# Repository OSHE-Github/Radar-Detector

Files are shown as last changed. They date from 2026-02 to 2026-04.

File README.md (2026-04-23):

# Radar-Detector

## Project Details
#### a fully open-source radar detector that can be easily replicated by others. Unlike existing commercial solutions, which are proprietary, this design will provide transparency, customization, and accessibility to users. By creating the first truly open-source radar detector, the project expands available options for individuals interested in building, modifying, or better understanding radar detection technology.
#### This device is powered by the 12V port that's in every commercial vehicle by using a 5V adapter and USB-C connector on board.

## Current State
#### The current Design includes
#### - Completed RF and Control Board
#### - Completed Antenna and Waveguide
#### - A breadboarded circuit for K band detection

## Semester End Report
#### For the Enterprise Program at Michigan Tech there is a end of semester report for the project to summarize the progress of the project. [Link](https://docs.google.com/document/d/1saLg0oObQiK9GF-1CGu6zWZuvDCvK0RMIuFfh2jqqCw/edit?usp=sharing)

## Relevant Standards
#### - Traces Were sized appropriately for current being drawn
#### - No traces can be ran under the main RF lines
#### - There was fusing put in front of the main power input from the USB-C
#### - Decoupling capacitors used to reduce noise from voltage sources going into sensitive components

## Constraints of Design
#### - when working with high frequencies up to 40GHz you have to use special small components that can handle it
#### - The material to make a PCB that can handle that high of frequencies is very expensive
#### - Amplifiers for this frequency are very expensive

## Next Semester Goals
#### - Look into possible cheaper solutions using modules like what we found for the K band
#### - Test the Ka band implementation once we have the antenna
#### - Look into the design on the component for the K band and see if parts of it are re-creatable

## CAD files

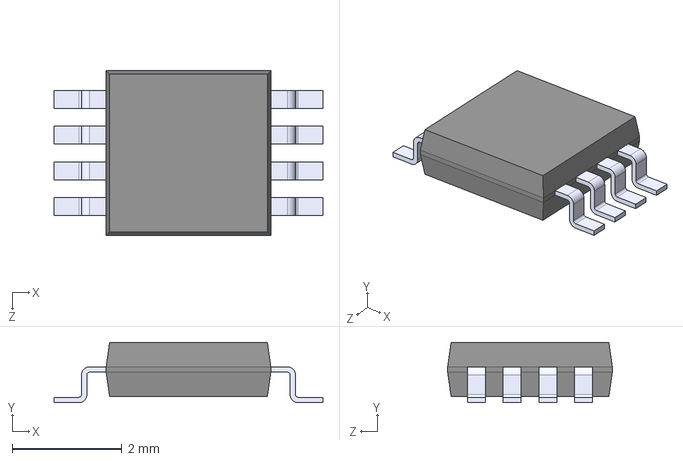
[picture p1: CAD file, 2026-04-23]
Front-End KiCad/Radar_Detector/FINAL - UPPER RF BOARD/AD8314ARMZ.step
4.90 x 1.10 x 3.00 mm

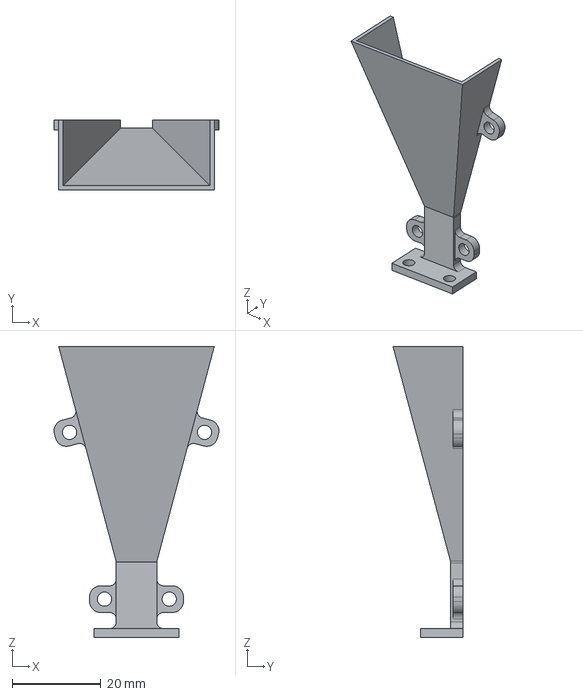
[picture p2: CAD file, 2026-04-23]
Horn Antenna/Horn Antenna & Waveguide Final/AntennaTOPFillet.step
37.1 x 15.8 x 65.4 mm

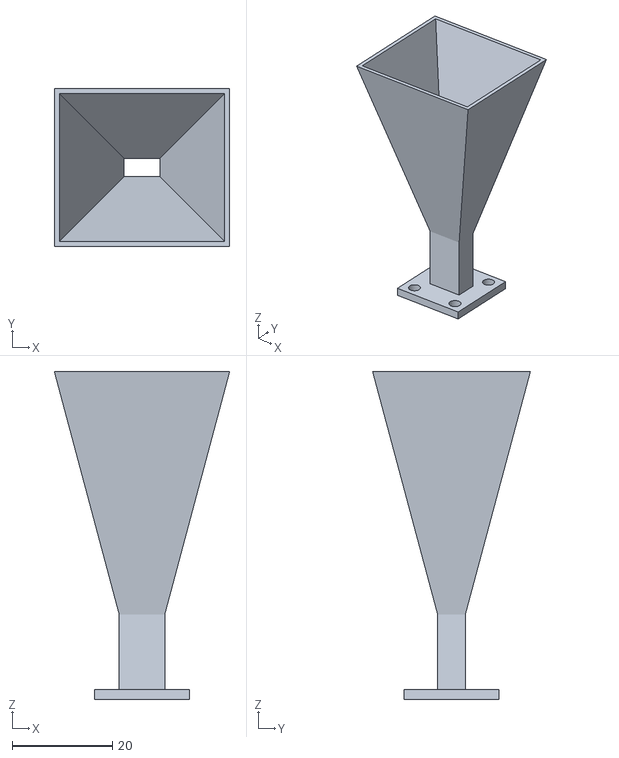
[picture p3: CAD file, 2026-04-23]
Horn Antenna/Horn Antenna V4/HornAntennaV4.stl
35.0 x 31.5 x 65.4

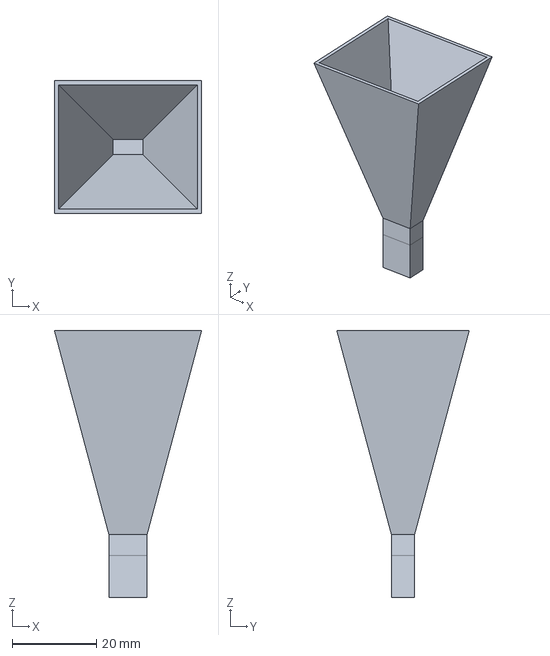
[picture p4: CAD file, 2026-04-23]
Horn Antenna/Horrn Antenna V5/HornAntennaV5_Rough Draft.FCStd
35.0 x 31.5 x 63.4 mm

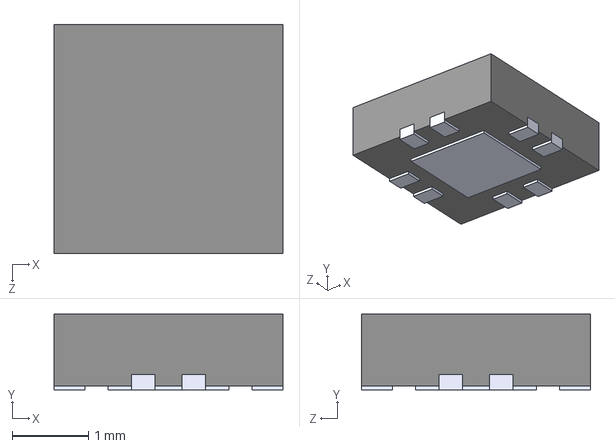
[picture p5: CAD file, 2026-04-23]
Front-End KiCad/Radar_Detector/FINAL - UPPER RF BOARD/PMA-5451_.step
3.00 x 0.99 x 3.00 mm

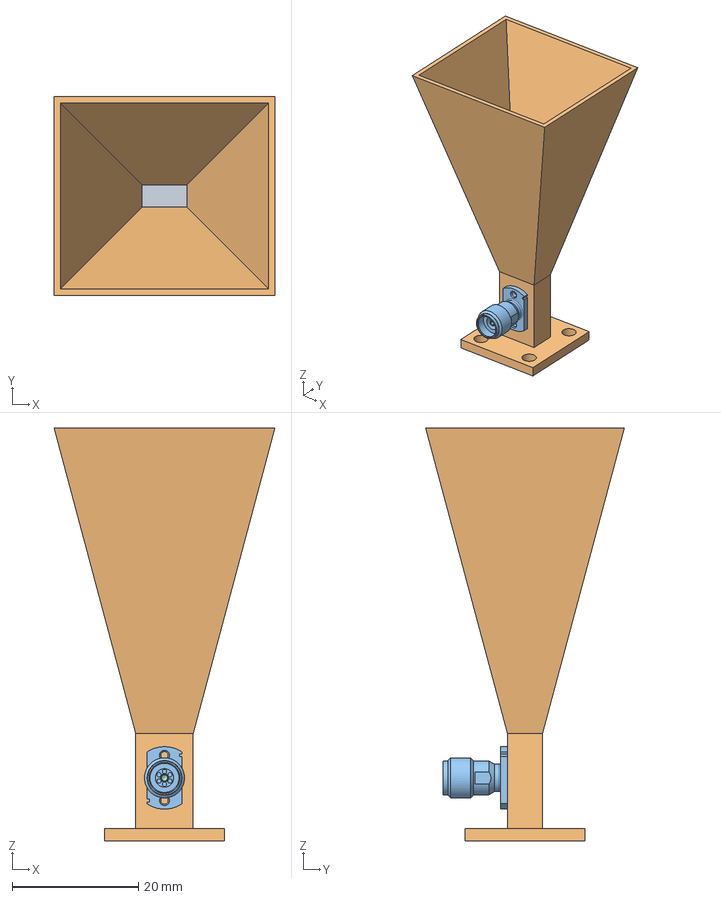
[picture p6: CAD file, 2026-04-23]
Horn Antenna/Horrn Antenna V5/HornAntennaV5_WithCOAX.FCStd
35.0 x 31.5 x 65.4 mm
292-J-P-EP-ST-CM-1_BODY
292-J-P-CM_PIN

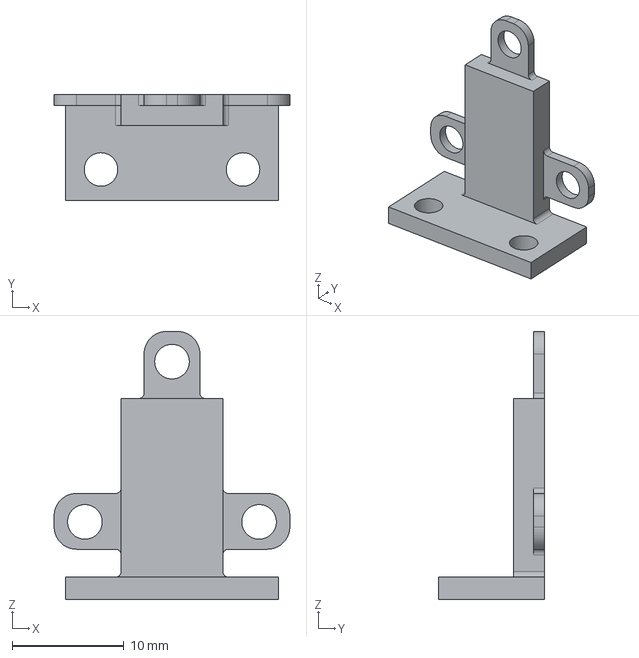
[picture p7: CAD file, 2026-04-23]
Horn Antenna/Horn Antenna & Waveguide Final/WaveguideBOTFillet.step
21.1 x 9.53 x 24.0 mm

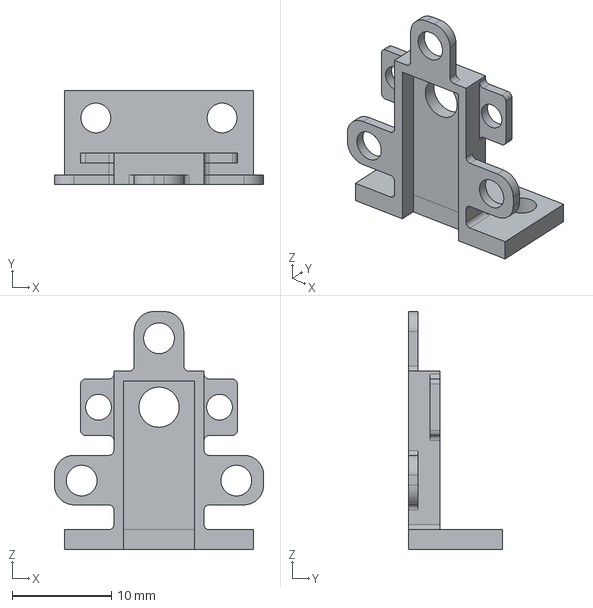
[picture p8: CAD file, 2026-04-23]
Horn Antenna/Horn Antenna & Waveguide Final/WaveguideTOPFillet.step
21.1 x 9.53 x 24.0 mm

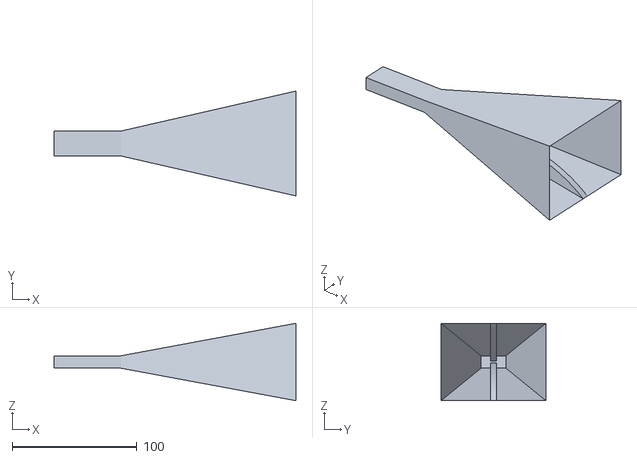
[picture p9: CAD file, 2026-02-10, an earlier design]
Horn Antenna/Horn Antenna V2/3D Models/8_40Ghz_Scaled.stl
193.8 x 84.0 x 62.0

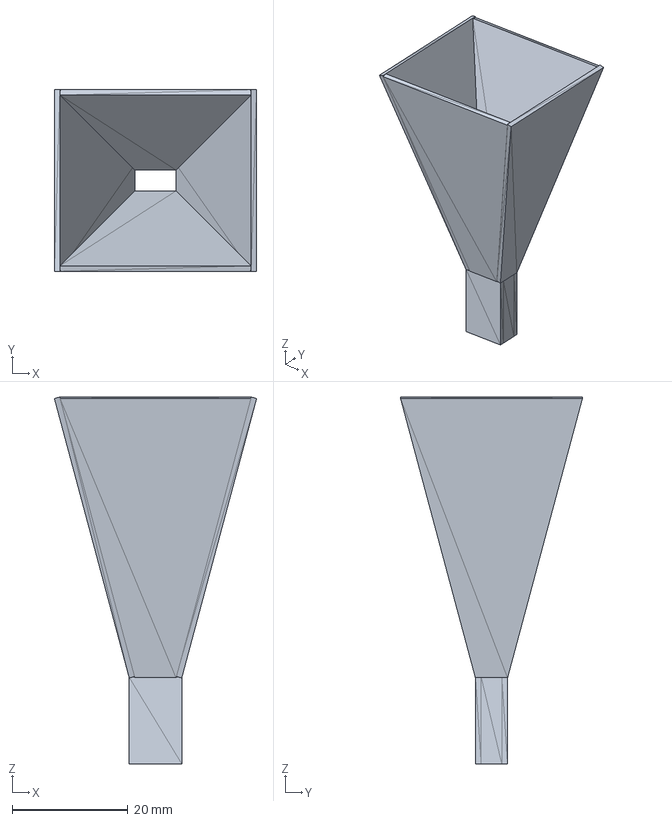
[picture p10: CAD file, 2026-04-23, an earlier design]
Horn Antenna/Horn Antenna V3/3D Models/HornAntennaKA.FCStd
35.0 x 31.4 x 63.4 mm

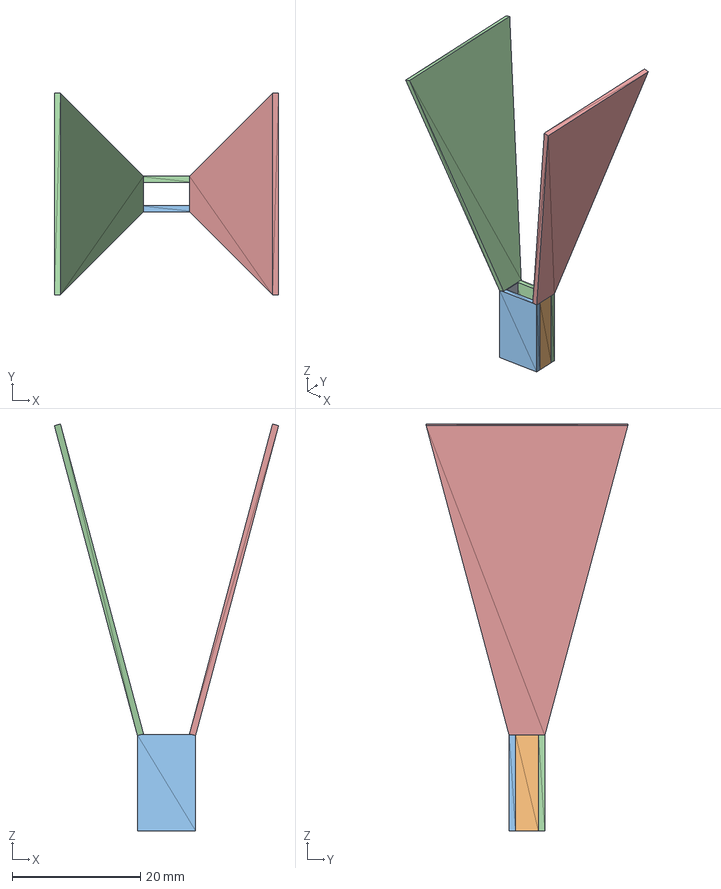
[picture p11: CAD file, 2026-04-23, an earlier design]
Horn Antenna/Horn Antenna V3/3D Models/Unnamed1.FCStd
35.0 x 31.4 x 63.4 mm

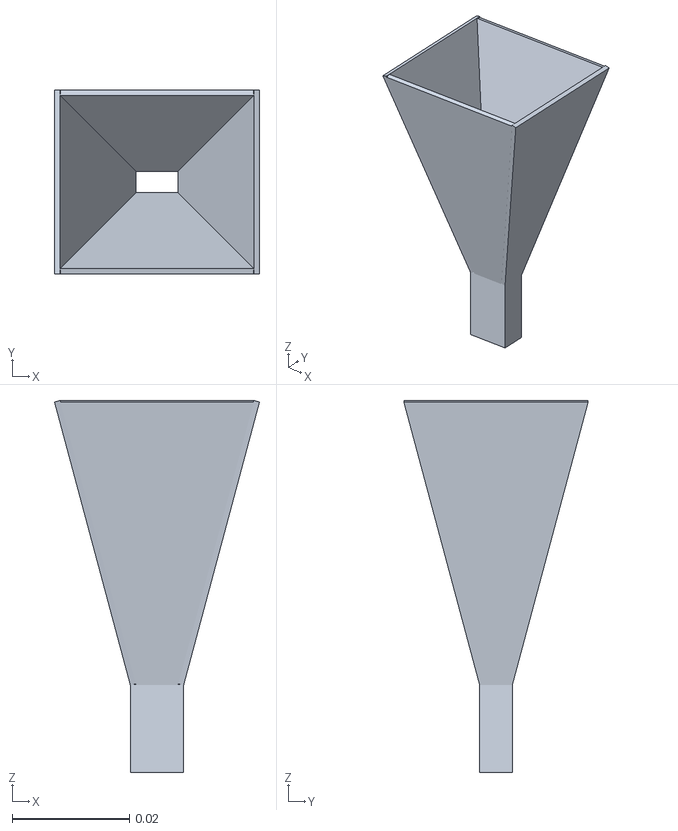
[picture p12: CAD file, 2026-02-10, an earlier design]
Horn Antenna/Horn Antenna V3/3D Models/horn.stl
0.035 x 0.0314 x 0.0634

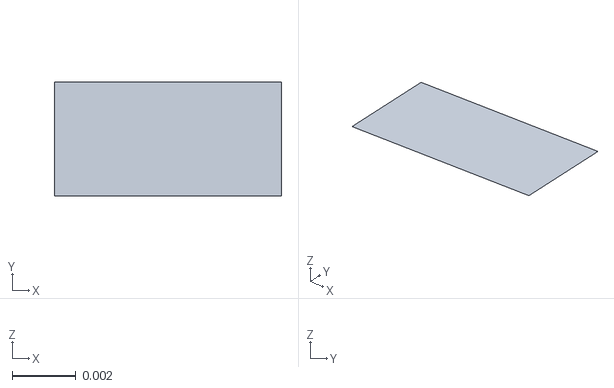
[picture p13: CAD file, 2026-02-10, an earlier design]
Horn Antenna/Horn Antenna V3/3D Models/port_excite_1.stl
0.00711 x 0.00356 x 0

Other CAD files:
Horn Antenna/Horn Antenna & Waveguide Final/AntennaBOTFillet.step
Horn Antenna/Horn Antenna V3/3D Models/Antenna.stp

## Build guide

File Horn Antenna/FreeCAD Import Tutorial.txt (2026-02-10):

How to Import the generated stl file into FreeCAD

1. Create New File, Parametric Part
2. Go to File and then press Import. (or press Ctrl + I)
3. Navigate to Correct Folder and open correct .stl File 

How to Convert Imported Mesh to Solid in FreeCAD

1. Switch Workbench
 1.A. In the top center dropdown menu (which usually says "Start"), switch to the Part Workbench. On modern Versions it may be called just Part

2. In Create Shape Tab
 2.A. Select the antenna mesh in the Model tree (on the left side of the screen).
 2.B. Select Object then, Go to the top menu: Part and Create shape from mesh.
 2.C. A popup will appear asking for "Tolerance for sewing shape." Leave it at 0.10 and click OK.

3. Convert to Solid 
 3.A. Open part menu on the top of the screen, press convert to solid 

4. Clean Up 
 4.A. Select Solid Object
 4.B. Click Part, Create Copy, Refine Shape

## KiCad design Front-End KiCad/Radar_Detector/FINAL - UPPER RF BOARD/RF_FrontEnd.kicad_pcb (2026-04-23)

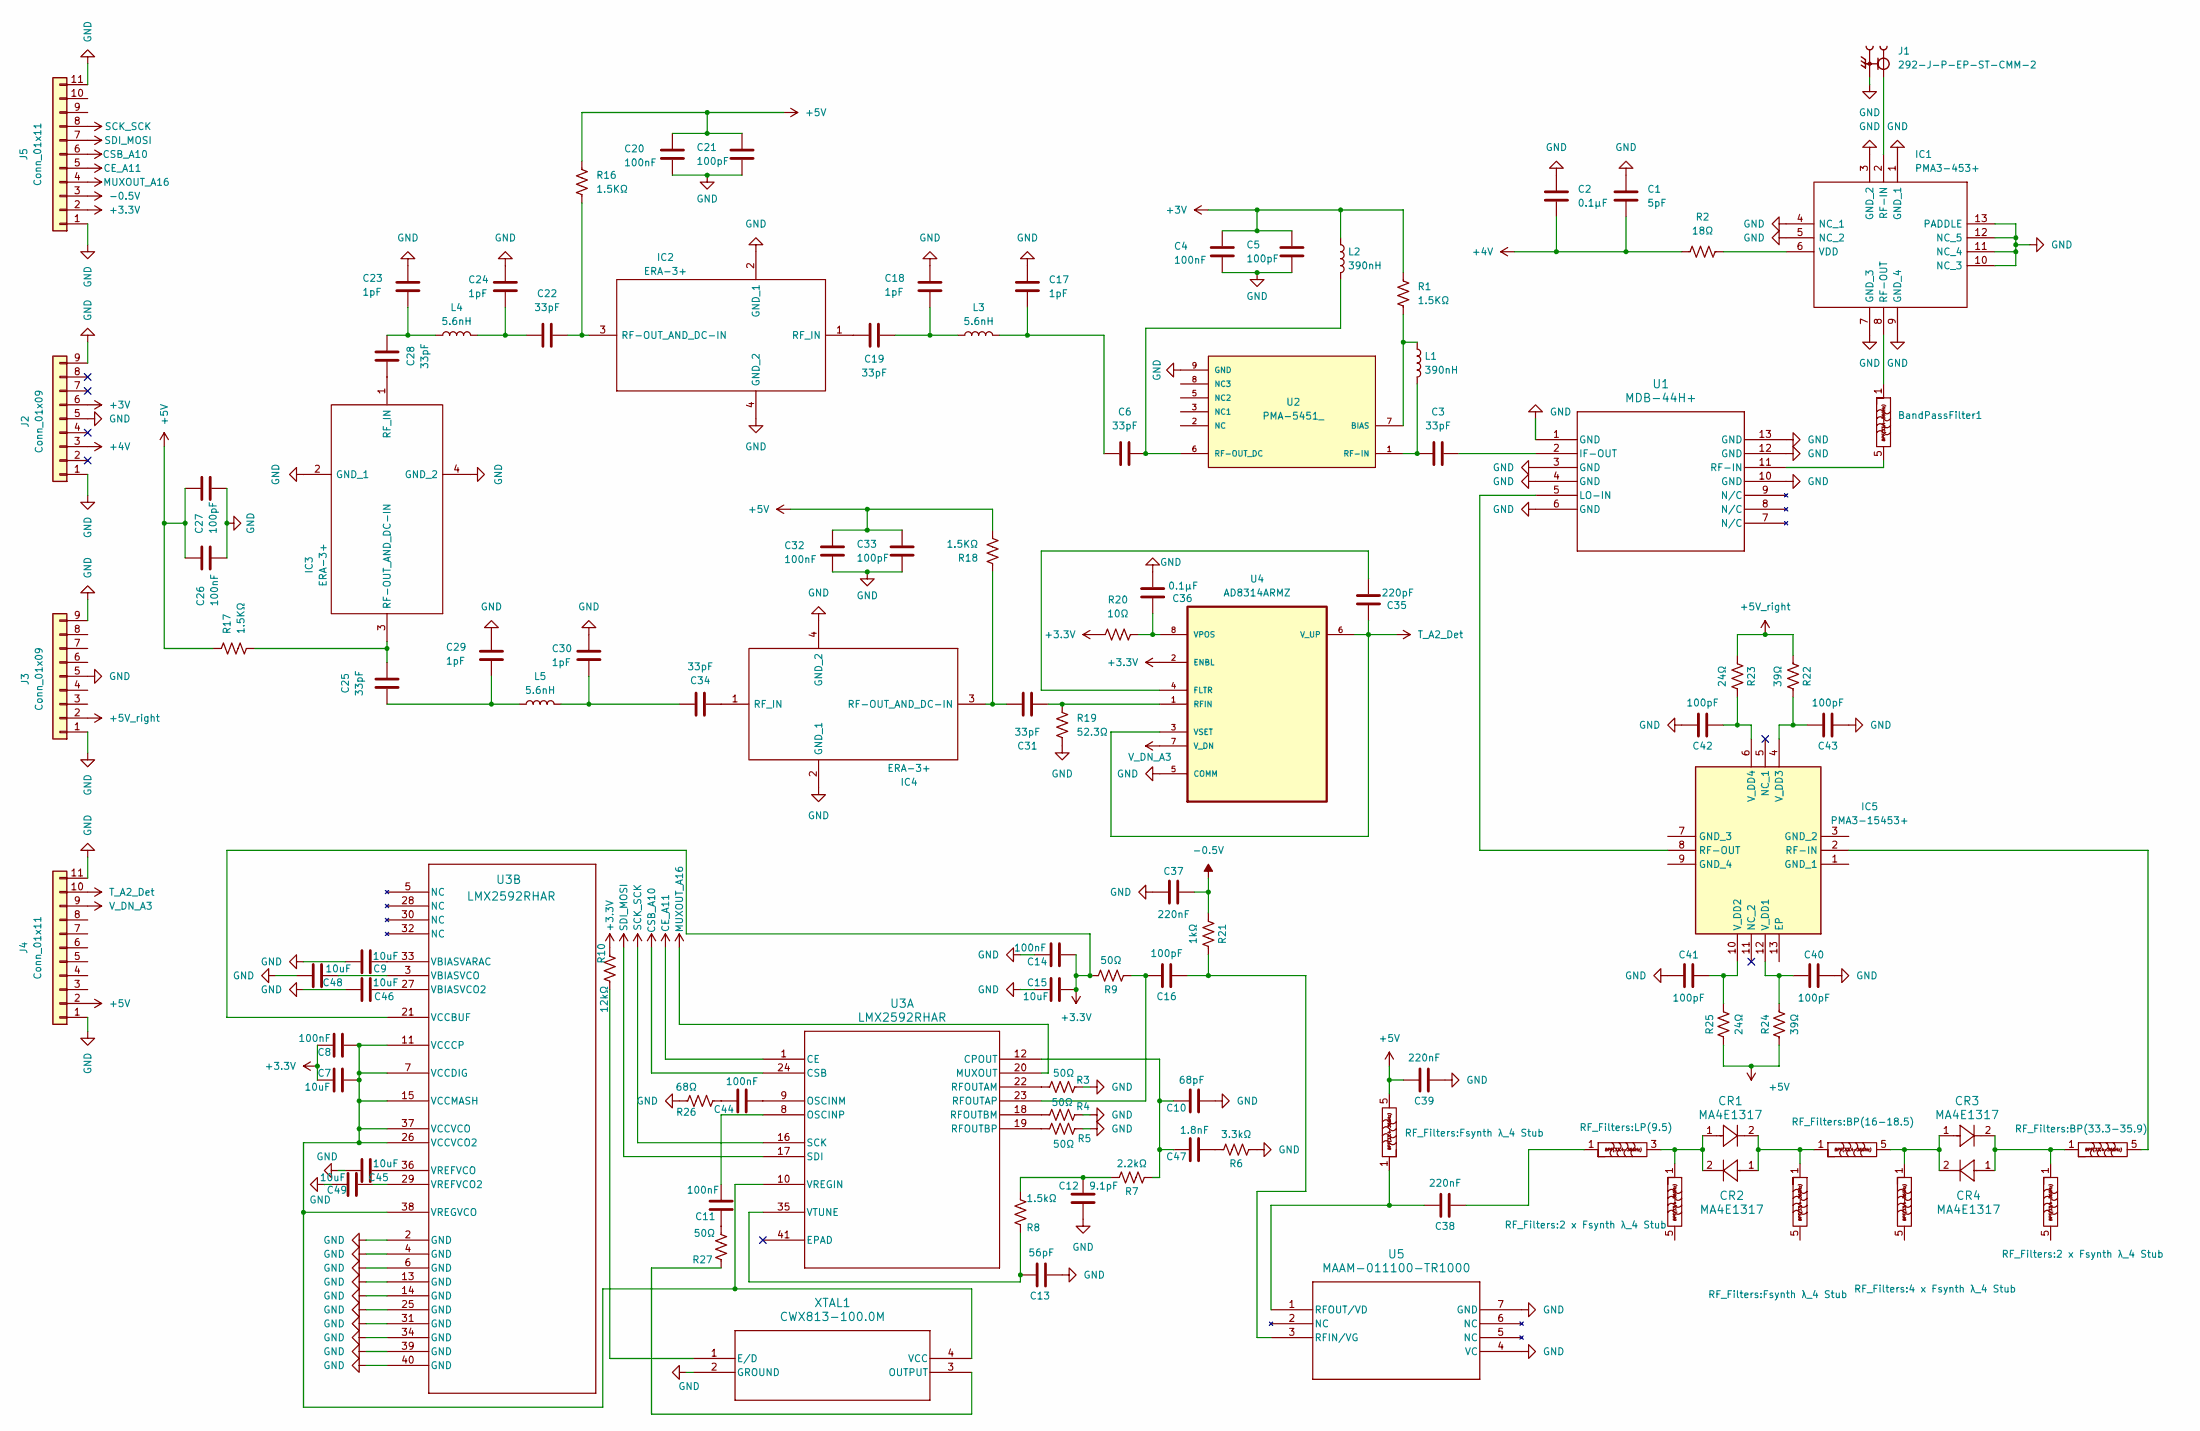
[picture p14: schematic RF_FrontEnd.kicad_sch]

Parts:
BandPassFilter1: BP(33.4-36)
BandPassFilter2: 16-18.5 GHz; BP(16-18.5)
BandPassFilter3: 33.3-35.9 GHz; BP(33.3-35.9)
BandPassFilter4: 16-18.5 GHz; LP(9.5)
BandPassFilter5, BandPassFilter7: 16-18.5 GHz; Fsynth λ_4 Stub
BandPassFilter6, BandPassFilter8: 16-18.5 GHz; 2 x Fsynth λ_4 Stub
BandPassFilter9: 16-18.5 GHz; 4 x Fsynth λ_4 Stub
C1: 5pF; C_0402_1005Metric_Pad0.74x0.62mm_HandSolder
C2, C36: 0.1μF; C_0402_1005Metric_Pad0.74x0.62mm_HandSolder
C3, C6, C19, C22, C25, C28, C31, C34: 33pF; C_0402_1005Metric_Pad0.74x0.62mm_HandSolder
C4, C8, C11, C14, C20, C26, C32, C44: 100nF; C_0402_1005Metric_Pad0.74x0.62mm_HandSolder
C5, C16, C21, C27, C33, C40, C41, C42, C43: 100pF; C_0402_1005Metric_Pad0.74x0.62mm_HandSolder
C7, C15: 10uF; C_0805_2012Metric_Pad1.18x1.45mm_HandSolder
C9, C45, C46, C48, C49: 10uF; C_0402_1005Metric_Pad0.74x0.62mm_HandSolder
C10: 68pF; C_0402_1005Metric_Pad0.74x0.62mm_HandSolder
C12: 9.1pF; C_0402_1005Metric_Pad0.74x0.62mm_HandSolder
C13: 56pF; C_0402_1005Metric_Pad0.74x0.62mm_HandSolder
C17, C18, C23, C24, C29, C30: 1pF; C_0402_1005Metric_Pad0.74x0.62mm_HandSolder
C35: 220pF; C_0402_1005Metric_Pad0.74x0.62mm_HandSolder
C37, C39: 220nF; C_0402_1005Metric_Pad0.74x0.62mm_HandSolder
C38: 220nF; C_0201_0603Metric_Pad0.64x0.40mm_HandSolder
C47: 1.8nF; C_0402_1005Metric_Pad0.74x0.62mm_HandSolder
CR1, CR2, CR3, CR4: MA4E1317; MA4E1317_1278_MCM
IC1: PMA3-453+; QFN51P300X300X89-13N; Manufacturer_Part_Number PMA3-453+; Mouser Part Number 139-PMA3-453+
IC2, IC3, IC4: ERA-3+; ERA3; Manufacturer_Part_Number ERA-3+; Mouser Part Number 139-ERA-3
IC5: PMA3-15453+; PMA315453; Mouser Part Number 139-PMA3-15453+
J1: 292-J-P-EP-ST-CMM-2; SAMTEC_292-J-P-EP-ST-CMM-2; PARTREV F
J2, J3: Conn_01x09; PinHeader_1x09_P2.54mm_Vertical
J4, J5: Conn_01x11; PinHeader_1x11_P2.54mm_Vertical
L1, L2: 390nH; L_0603_1608Metric_Pad1.05x0.95mm_HandSolder
L3, L4, L5: 5.6nH; L_0402_1005Metric_Pad0.77x0.64mm_HandSolder
R1: 1.5KΩ; R_0402_1005Metric_Pad0.72x0.64mm_HandSolder
R2: 18Ω; R_0603_1608Metric_Pad0.98x0.95mm_HandSolder
R3, R4, R5: 50Ω; R_0603_1608Metric_Pad0.98x0.95mm_HandSolder
R6: 3.3kΩ; R_0402_1005Metric_Pad0.72x0.64mm_HandSolder
R7: 2.2kΩ; R_0402_1005Metric_Pad0.72x0.64mm_HandSolder
R8: 1.5kΩ; R_0402_1005Metric_Pad0.72x0.64mm_HandSolder
R9, R27: 50Ω; R_0402_1005Metric_Pad0.72x0.64mm_HandSolder
R10: 12kΩ; R_0402_1005Metric_Pad0.72x0.64mm_HandSolder
R16, R17, R18: 1.5KΩ; R_0603_1608Metric_Pad0.98x0.95mm_HandSolder
R19: 52.3Ω; R_0402_1005Metric_Pad0.72x0.64mm_HandSolder
R20: 10Ω; R_0402_1005Metric_Pad0.72x0.64mm_HandSolder
R21: 1kΩ; R_0402_1005Metric_Pad0.72x0.64mm_HandSolder
R22, R24: 39Ω; R_0603_1608Metric_Pad0.98x0.95mm_HandSolder
R23, R25: 24Ω; R_0603_1608Metric_Pad0.98x0.95mm_HandSolder
R26: 68Ω; R_0402_1005Metric_Pad0.72x0.64mm_HandSolder
U1: MDB-44H+; DQ1225_MNC
U2: PMA-5451_; QFN66P300X300X99-9N; PARTREV M
U3: LMX2592RHAR; RHA40_TEX
U4: AD8314ARMZ; SOP65P490X110-8N; MPN AD8314ARMZ
U5: MAAM-011100-TR1000; TDFN6_1.5X1.2_MCM
XTAL1: CWX813-100.0M; CWX813-100.0M_CNW

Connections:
+3.3V: C7.1, C8.1, C14.2, C15.2, J5.2, R9.2, R10.1, R20.2, U3.21 (VCCBUF), U4.2 (ENBL)
+3V: C4.1, C5.1, J2.6, L2.1, R1.2
+4V: C1.2, C2.2, J2.3, R2.1
+5V: BandPassFilter5.5, C20.1, C21.1, C26.1, C27.1, C32.1, C33.1, C39.1, J4.2, R16.2, R17.2, R18.1, R24.1, R25.1
+5V_right: J3.2, R22.1, R23.1
-0.5V: C37.1, J5.3, R21.1
CE_A11: J5.5, U3.1 (CE)
CSB_A10: J5.6, U3.24 (CSB)
GND: C1.1, C2.1, C4.2, C5.2, C9.2, C10.2, C12.2, C13.2, C14.1, C15.1, C17.2, C18.2, C20.2, C21.2, C23.2, C24.2, C26.2, C27.2, C29.2, C30.2, C32.2, C33.2, C36.2, C37.2, C39.2, C40.1, C41.2, C42.1, C43.2, C45.2, C46.2, C48.1, C49.1, IC1.1 (GND_1), IC1.3 (GND_2), IC1.4 (NC_1), IC1.5 (NC_2), IC1.7 (GND_3), IC1.9 (GND_4), IC1.10 (NC_3), IC1.11 (NC_4), IC1.12 (NC_5), IC1.13 (PADDLE), IC2.2 (GND_1), IC2.4 (GND_2), IC3.2 (GND_1), IC3.4 (GND_2), IC4.2 (GND_1), IC4.4 (GND_2), J1.G1, J2.1, J2.5, J2.9, J3.1, J3.5, J3.9, J4.1, J4.11, J5.1, J5.11, R3.1, R4.1, R5.1, R6.1, R19.1, R26.2, U1.1 (GND), U1.3 (GND), U1.4 (GND), U1.6 (GND), U1.10 (GND), U1.12 (GND), U1.13 (GND), U2.9 (GND), U3.2 (GND), U3.4 (GND), U3.6 (GND), U3.13 (GND), U3.14 (GND), U3.25 (GND), U3.31 (GND), U3.34 (GND), U3.39 (GND), U3.40 (GND), U3.41 (EPAD), U3.V, U4.5 (COMM), U5.4 (VC), U5.7 (GND), XTAL1.2 (GROUND)
MUXOUT_A16: J5.4, U3.20 (MUXOUT)
unnamed: BandPassFilter2.1, BandPassFilter7.1, CR1.2, CR2.1
unnamed: BandPassFilter2.5, BandPassFilter9.1, CR3.1, CR4.2
unnamed: BandPassFilter3.1, BandPassFilter8.1, CR3.2, CR4.1
unnamed: BandPassFilter4.1, C38.2
unnamed: BandPassFilter4.3, BandPassFilter6.1, CR1.1, CR2.2
unnamed: C11.2, R27.2
unnamed: C12.1, R7.2, R8.2
unnamed: C6.1, C17.1, L3.2
unnamed: C18.1, C19.2, L3.1
unnamed: C22.1, C24.1, L4.2
unnamed: C23.1, C28.2, L4.1
unnamed: C25.1, C29.1, L5.1
unnamed: C30.1, C34.2, L5.2
unnamed: C44.2, R26.1
unnamed: C47.2, R6.2
unnamed: IC1.2 (RF-IN), J1.1
unnamed: BandPassFilter1.1, IC1.8 (RF-OUT)
unnamed: IC1.6 (VDD), R2.2
unnamed: C22.2, IC2.3 (RF-OUT_AND_DC-IN), R16.1
unnamed: C19.1, IC2.1 (RF_IN)
unnamed: C25.2, IC3.3 (RF-OUT_AND_DC-IN), R17.1
unnamed: C28.1, IC3.1 (RF_IN)
unnamed: C31.2, IC4.3 (RF-OUT_AND_DC-IN), R18.2
unnamed: C34.1, IC4.1 (RF_IN)
unnamed: BandPassFilter3.5, IC5.2 (RF-IN)
unnamed: IC5.8 (RF-OUT), U1.5 (LO-IN)
unnamed: C40.2, IC5.12 (V_DD1), R24.2
unnamed: C41.1, IC5.10 (V_DD2), R25.2
unnamed: C43.1, IC5.4 (V_DD3), R22.2
unnamed: C42.2, IC5.6 (V_DD4), R23.2
unnamed: C3.2, U1.2 (IF-OUT)
unnamed: BandPassFilter1.5, U1.11 (RF-IN)
unnamed: L1.1, R1.1, U2.7 (BIAS)
unnamed: U2.3 (NC1), U2.4 (NC1)
unnamed: C3.1, L1.2, U2.1 (RF-IN)
unnamed: C6.2, L2.2, U2.6 (RF-OUT_DC)
unnamed: C10.1, C47.1, R7.1, U3.12 (CPOUT)
unnamed: C44.1, U3.9 (OSCINM)
unnamed: C11.1, U3.8 (OSCINP)
unnamed: R3.2, U3.22 (RFOUTAM)
unnamed: C16.1, R9.1, U3.23 (RFOUTAP)
unnamed: R4.2, U3.18 (RFOUTBM)
unnamed: R5.2, U3.19 (RFOUTBP)
unnamed: C7.2, C8.2, U3.7 (VCCDIG), U3.10 (VREGIN), U3.11 (VCCCP), U3.15 (VCCMASH), U3.26 (VCCVCO2), U3.37 (VCCVCO), U3.38 (VREGVCO), XTAL1.4 (VCC)
unnamed: C13.1, R8.1, U3.35 (VTUNE)
unnamed: C9.1, U3.33 (VBIASVARAC)
unnamed: C46.1, U3.27 (VBIASVCO2)
unnamed: C48.2, U3.3 (VBIASVCO)
unnamed: C49.2, U3.29 (VREFVCO2)
unnamed: C45.1, U3.36 (VREFVCO)
unnamed: C35.2, U4.4 (FLTR)
unnamed: C31.1, R19.2, U4.1 (RFIN)
unnamed: C36.1, R20.1, U4.8 (VPOS)
unnamed: C16.2, R21.2, U5.3 (RFIN/VG)
unnamed: BandPassFilter5.1, C38.1, U5.1 (RFOUT/VD)
unnamed: R10.2, XTAL1.1 (E/D)
unnamed: R27.1, XTAL1.3 (OUTPUT)
SCK_SCK: J5.8, U3.16 (SCK)
SDI_MOSI: J5.7, U3.17 (SDI)
T_A2_Det: C35.1, J4.10, U4.3 (VSET), U4.6 (V_UP)
V_DN_A3: J4.9, U4.7 (V_DN)

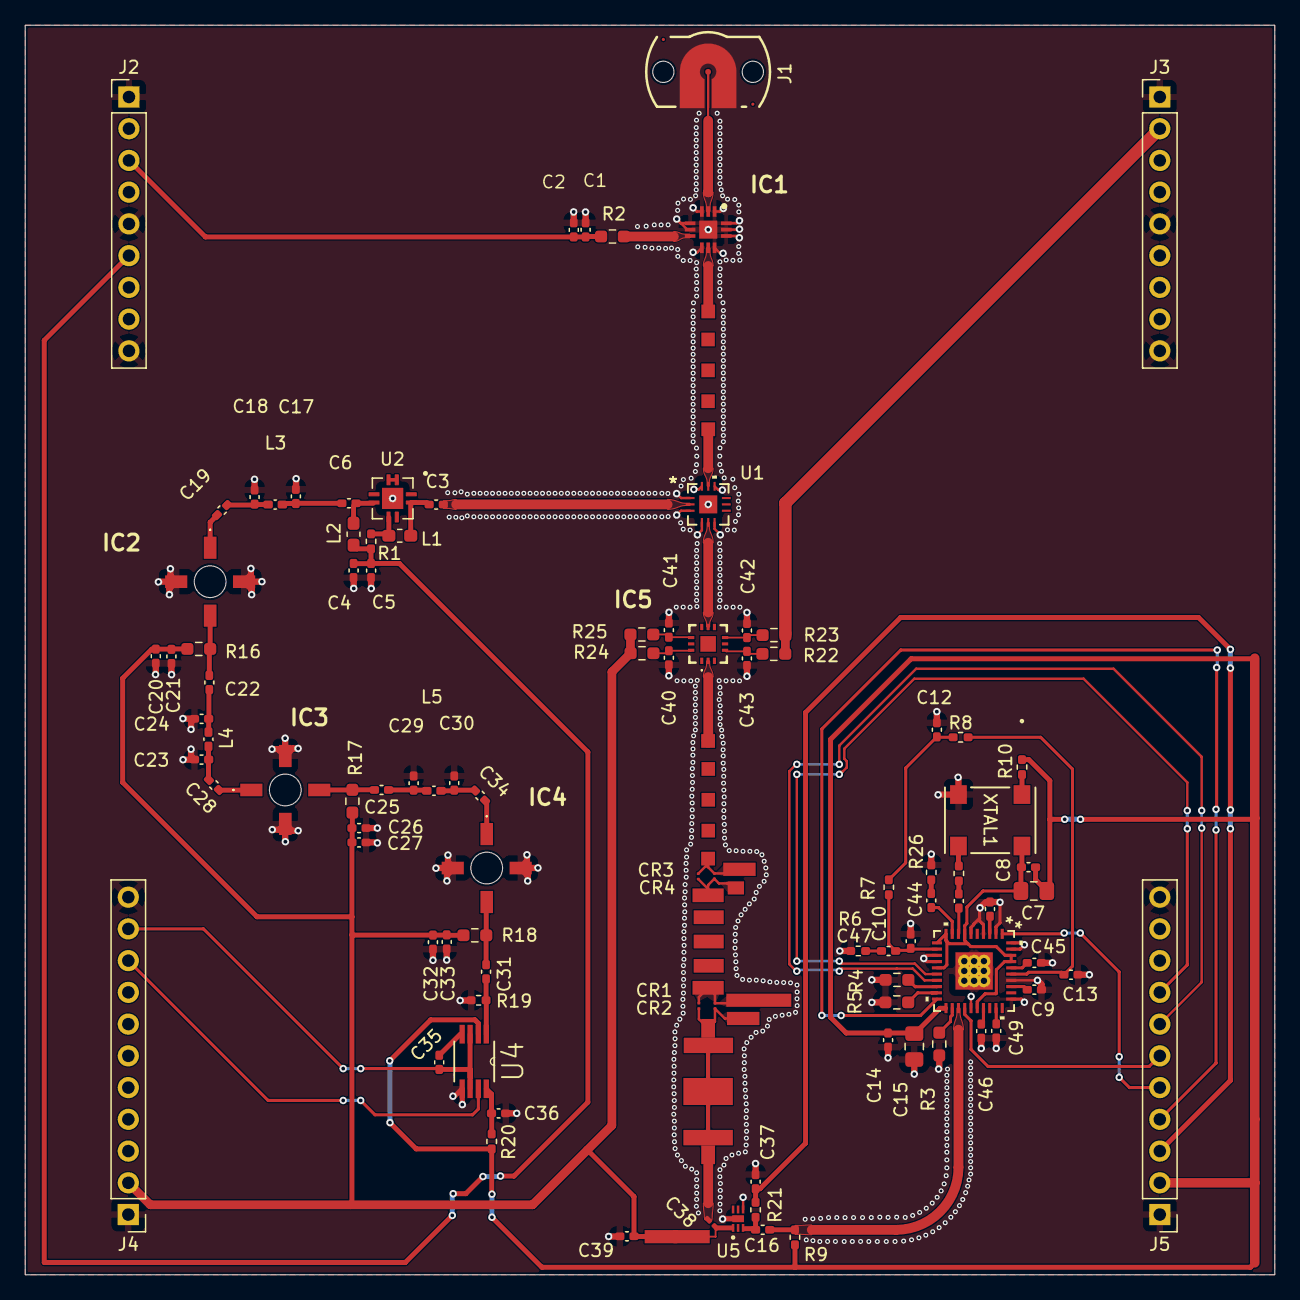
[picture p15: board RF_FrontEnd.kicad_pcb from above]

Board: 2 copper layers, 100.0 x 100.0 mm, 105 parts (0 on the bottom side), 71 nets.

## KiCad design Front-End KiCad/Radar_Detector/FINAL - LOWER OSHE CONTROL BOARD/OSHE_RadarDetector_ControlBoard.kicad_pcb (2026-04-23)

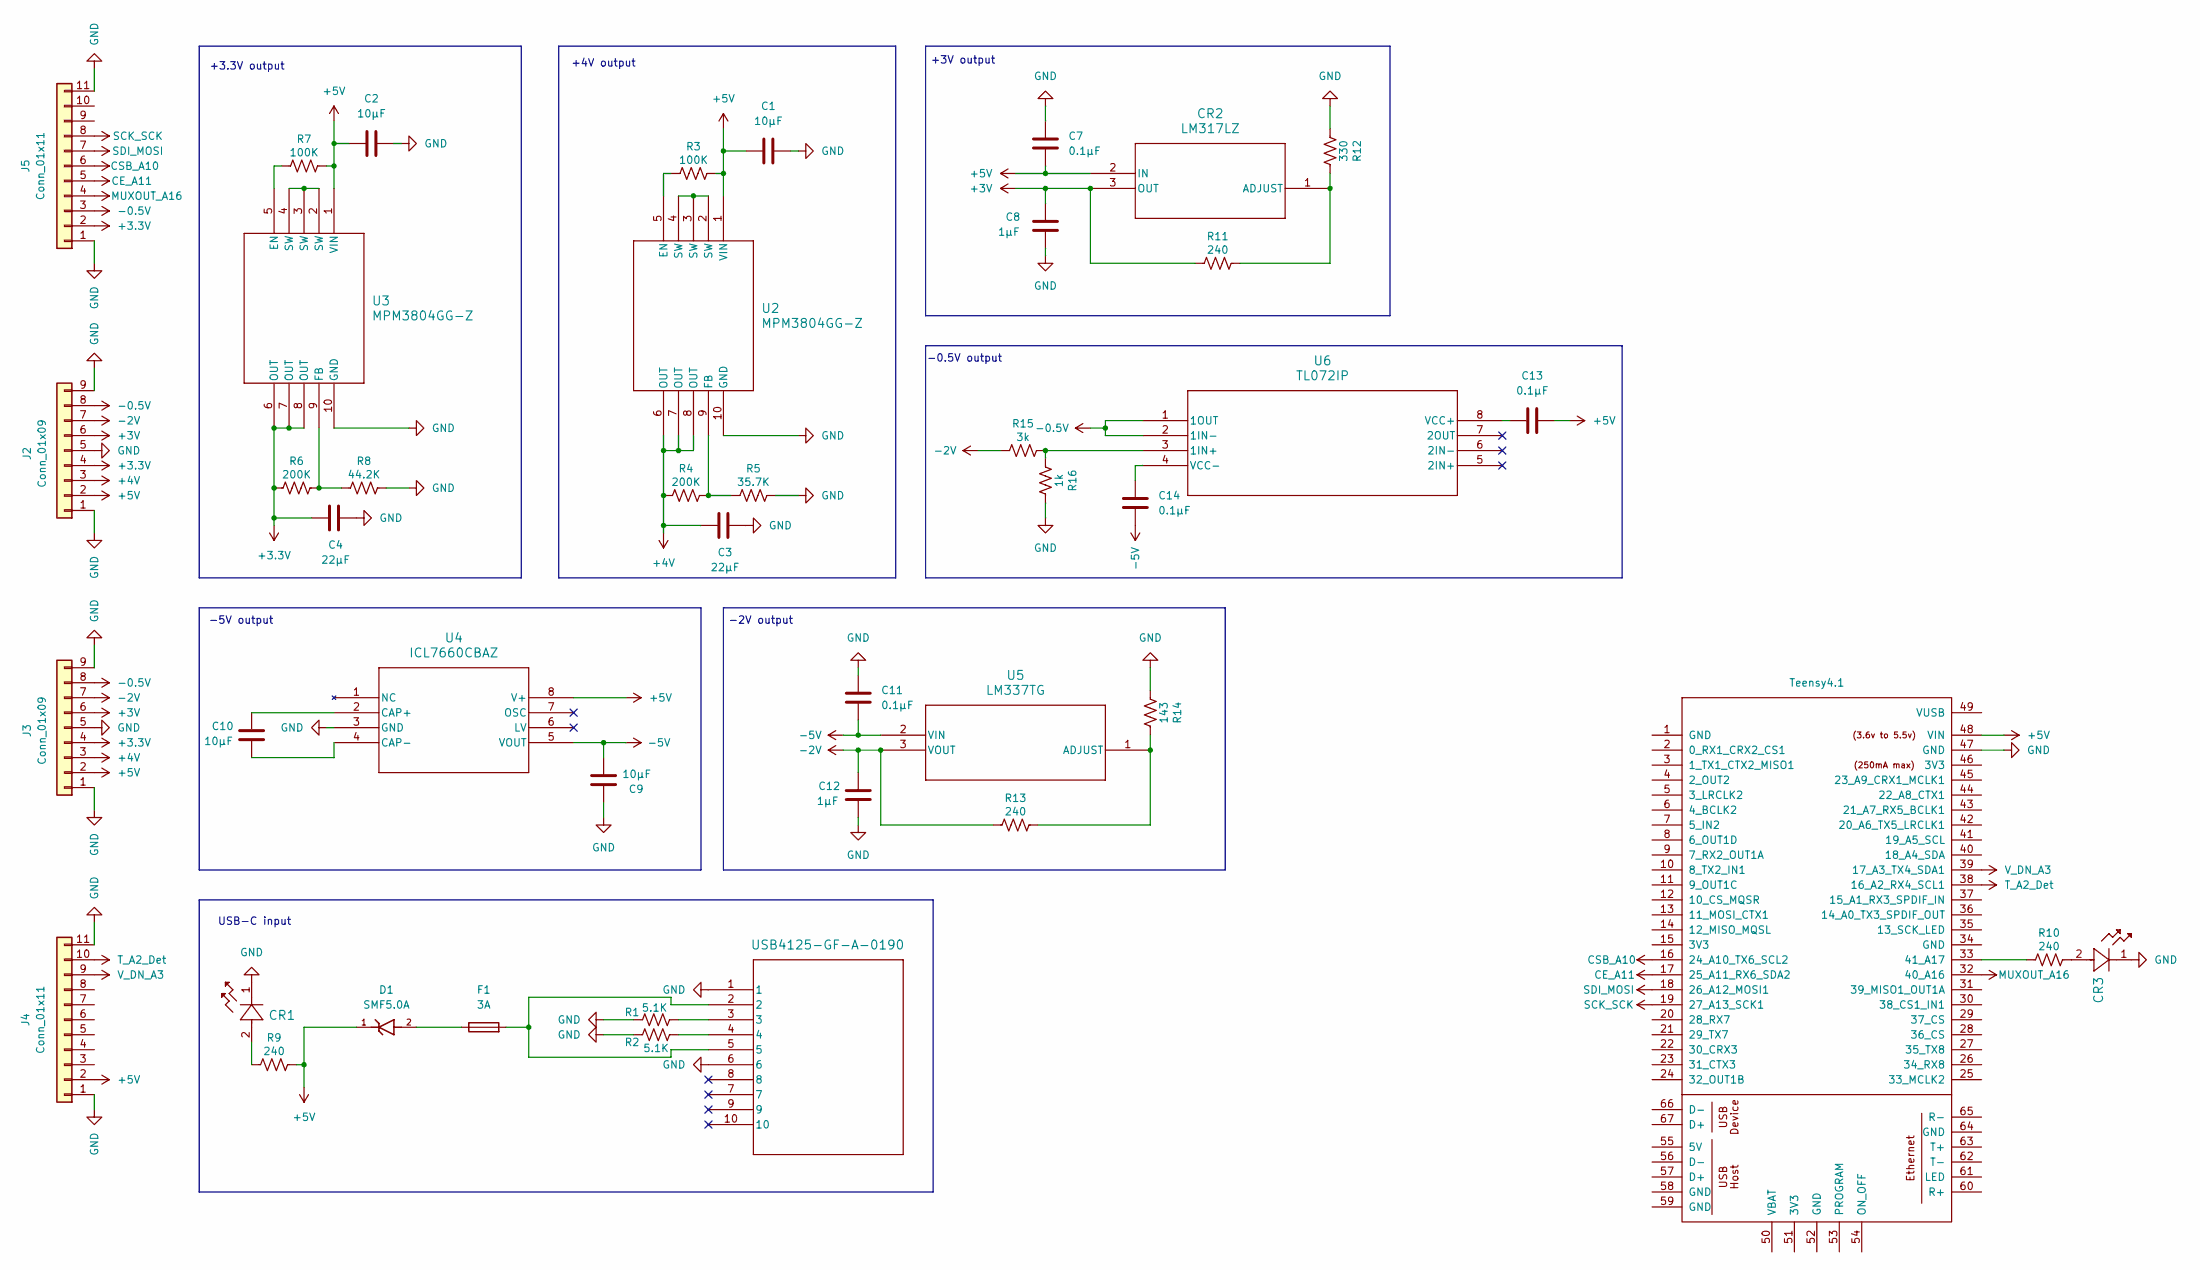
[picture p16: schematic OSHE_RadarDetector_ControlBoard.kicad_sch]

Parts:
C1, C2: 10μF; C_0603_1608Metric_Pad1.08x0.95mm_HandSolder
C3, C4: 22μF; C_0805_2012Metric_Pad1.18x1.45mm_HandSolder
C7, C11, C13, C14: 0.1μF; CP_Radial_D5.0mm_P2.50mm
C8, C12: 1μF; CP_Radial_D5.0mm_P2.50mm
C9, C10: 10μF; CP_Radial_D5.0mm_P2.50mm
CR1, CR3: C503B-GCN-CY0C0791; C503B
CR2: LM317LZ; TO-92_STM
D1: SMF5.0A; TVS_SMF5.0A; PARTREV JC
F1: 3A; Fuse_0603_1608Metric_Pad1.05x0.95mm_HandSolder
J1: USB4125-GF-A-0190; CONN6_125-GF-A-0190_GCT
J2, J3: Conn_01x09; PinHeader_1x09_P2.54mm_Vertical
J4, J5: Conn_01x11; PinHeader_1x11_P2.54mm_Vertical
R1, R2: 5.1K; R_0603_1608Metric_Pad0.98x0.95mm_HandSolder
R3, R7: 100K; R_1206_3216Metric_Pad1.30x1.75mm_HandSolder
R4, R6: 200K; R_1206_3216Metric_Pad1.30x1.75mm_HandSolder
R5: 35.7K; R_1206_3216Metric_Pad1.30x1.75mm_HandSolder
R8: 44.2K; R_1206_3216Metric_Pad1.30x1.75mm_HandSolder
R9, R10, R11, R13: 240; R_Axial_DIN0207_L6.3mm_D2.5mm_P7.62mm_Horizontal
R12: 330; R_Axial_DIN0207_L6.3mm_D2.5mm_P7.62mm_Horizontal
R14: 143; R_Axial_DIN0207_L6.3mm_D2.5mm_P7.62mm_Horizontal
R15: 3k; R_Axial_DIN0207_L6.3mm_D2.5mm_P7.62mm_Horizontal
R16: 1k; R_Axial_DIN0207_L6.3mm_D2.5mm_P7.62mm_Horizontal
U1: Teensy4.1; Teensy41
U2, U3: MPM3804GG-Z; QFN2p0x2p0x0p9_MNP
U4: ICL7660CBAZ; SOIC8_4X5_INR
U5: LM337TG; TO220AB-3_ONS
U6: TL072IP; P8

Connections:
+3.3V: C4.1, J2.4, J3.4, J5.2, R6.1, U3.6 (OUT), U3.7 (OUT), U3.8 (OUT); also elsewhere on the board
+3V: C8.2, CR2.3 (OUT), J2.6, J3.6, R11.1; also elsewhere on the board
+4V: C3.1, J2.3, J3.3, R4.1, U2.6 (OUT), U2.7 (OUT), U2.8 (OUT); also elsewhere on the board
+5V: C1.1, C2.1, C7.1, C13.1, CR2.2 (IN), D1.1, J2.2, J3.2, J4.2, R3.2, R7.2, R9.2, U1.48 (VIN), U2.1 (VIN), U3.1 (VIN), U4.8 (V+); also elsewhere on the board
-0.5V: J2.8, J3.8, J5.3, U6.1 (1OUT), U6.2 (1IN-); also elsewhere on the board
-2V: C12.2, J2.7, J3.7, R13.1, R15.1, U5.3 (VOUT); also elsewhere on the board
-5V: C9.1, C11.1, C14.2, U4.5 (VOUT), U5.2 (VIN)
CE_A11: J5.5, U1.17 (25_A11_RX6_SDA2)
CSB_A10: J5.6, U1.16 (24_A10_TX6_SCL2)
GND: C1.2, C2.2, C3.2, C4.2, C7.2, C8.1, C9.2, C11.2, C12.1, CR1.1, CR3.1, J1.1, J1.6, J2.1, J2.5, J2.9, J3.1, J3.5, J3.9, J4.1, J4.11, J5.1, J5.11, R1.1, R2.1, R5.2, R8.2, R12.1, R14.1, R16.2, U1.47 (GND), U2.10 (GND), U3.10 (GND), U4.3 (GND); also elsewhere on the board
MUXOUT_A16: J5.4, U1.32 (40_A16)
unnamed: CR1.2, R9.1
unnamed: CR2.1 (ADJUST), R11.2, R12.2
unnamed: CR3.2, R10.2
unnamed: D1.2, F1.1
unnamed: F1.2, J1.2, J1.5
unnamed: J1.3, R1.2
unnamed: J1.4, R2.2
unnamed: R10.1, U1.33 (41_A17)
unnamed: R3.1, U2.5 (EN)
unnamed: R4.2, R5.1, U2.9 (FB)
unnamed: U2.2 (SW), U2.3 (SW), U2.4 (SW)
unnamed: R7.1, U3.5 (EN)
unnamed: R6.2, R8.1, U3.9 (FB)
unnamed: U3.2 (SW), U3.3 (SW), U3.4 (SW)
unnamed: C10.2, U4.2 (CAP+)
unnamed: C10.1, U4.4 (CAP-)
unnamed: R13.2, R14.2, U5.1 (ADJUST)
unnamed: R15.2, R16.1, U6.3 (1IN+)
unnamed: C13.2, U6.8 (VCC+)
unnamed: C14.1, U6.4 (VCC-)
SCK_SCK: J5.8, U1.19 (27_A13_SCK1)
SDI_MOSI: J5.7, U1.18 (26_A12_MOSI1)
T_A2_Det: J4.10, U1.38 (16_A2_RX4_SCL1)
V_DN_A3: J4.9, U1.39 (17_A3_TX4_SDA1)

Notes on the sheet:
-2V output
-0.5V output
+3V output
+3.3V output
-5V output
+4V output
USB-C input

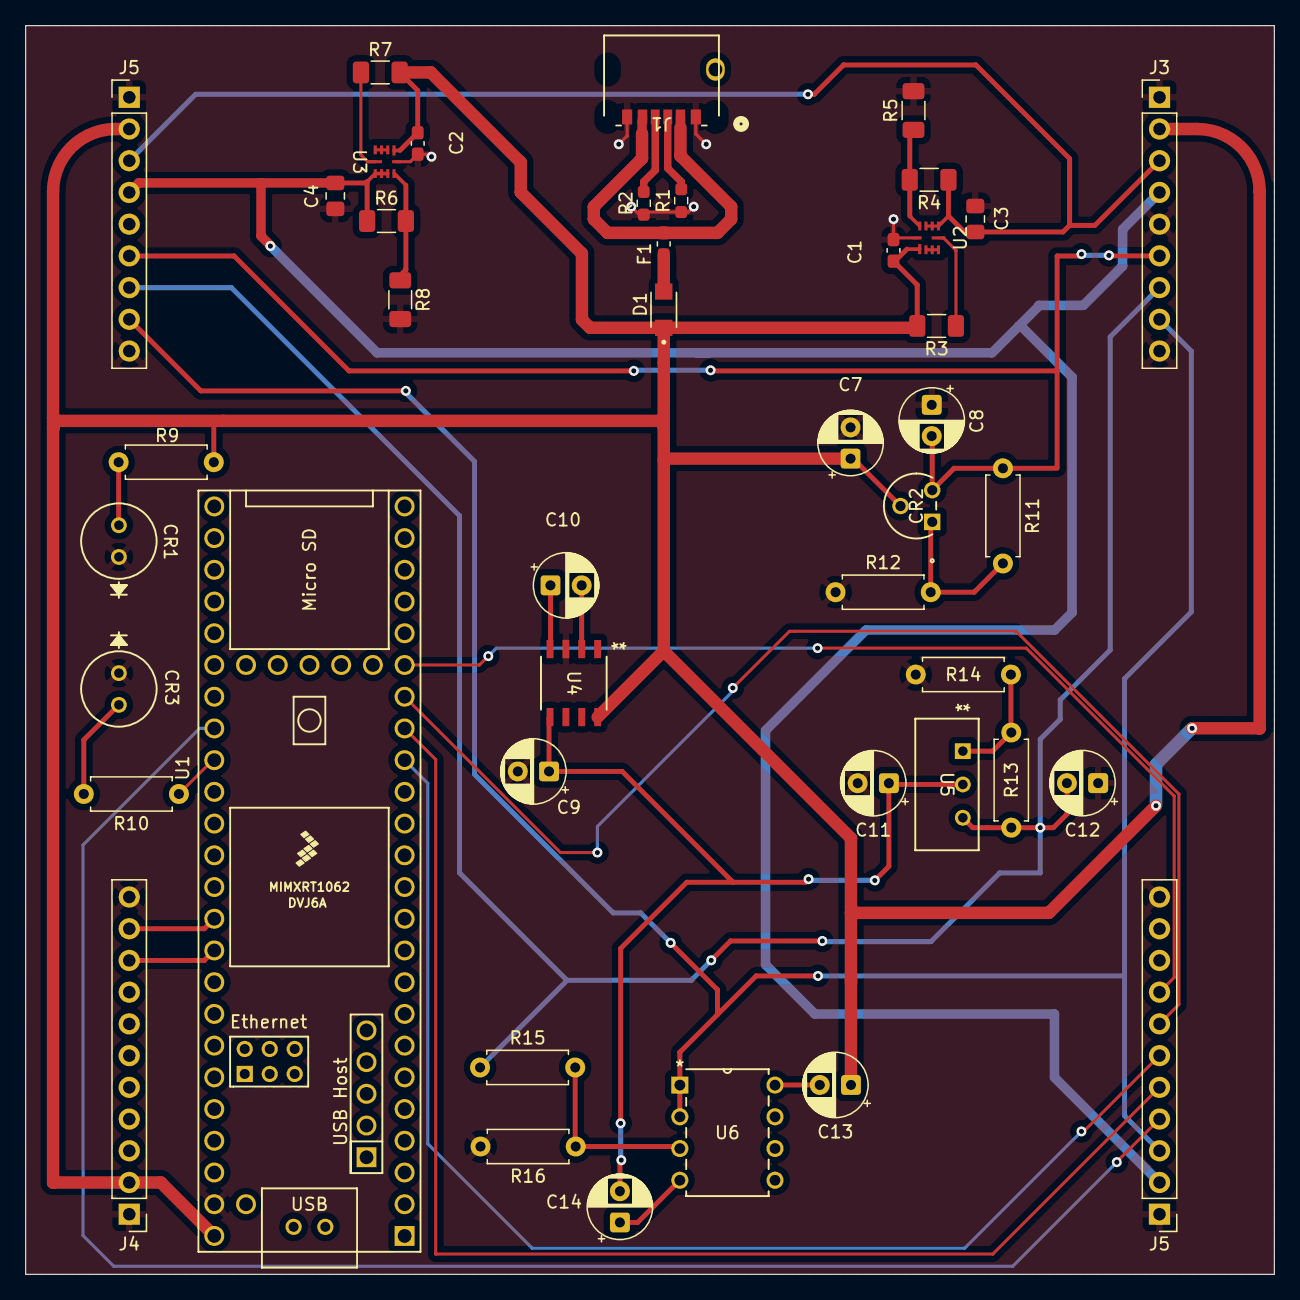
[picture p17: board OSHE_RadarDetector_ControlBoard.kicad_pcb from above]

Board: 2 copper layers, 100.0 x 100.0 mm, 44 parts (0 on the bottom side), 35 nets.

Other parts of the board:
J5#2: Conn_01x09; PinHeader_1x09_P2.54mm_Vertical

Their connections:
+3.3V: J5#2.4; also elsewhere on the board
+3V: J5#2.6; also elsewhere on the board
+4V: J5#2.3; also elsewhere on the board
+5V: J5#2.2; also elsewhere on the board
-0.5V: J5#2.8; also elsewhere on the board
-2V: J5#2.7; also elsewhere on the board
GND: J5#2.1, J5#2.9; also elsewhere on the board

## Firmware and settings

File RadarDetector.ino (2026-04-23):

//Includes
#include <SPI.h>

//Detector to Microcontroller connections
int Detector_V_UP = 16; // Analog value from 0-1V based on strength of signal detected
int Detector_V_DN = 17; // inverse V_UP signal so 1-0V based on signal strength detected

//Synthesizer to Microcontroller connections
int CSB_A10  = 24;
int CE_A11   = 25;
int SDI_MOSI = 26;
int SCK_SCK  = 27;
int Muxout   = 40;

//Microcontroller to LED
int LED_RED = 41;

void setup() 
{
  pinMode(LED_RED, OUTPUT);

  Serial.begin(115200);

  // AD8314 analog inputs
  pinMode(Detector_V_UP, INPUT);
  pinMode(Detector_V_DN, INPUT);

  // LMX2592 control pins
  pinMode(CSB_A10, OUTPUT);
  pinMode(CE_A11, OUTPUT);
  pinMode(Muxout, INPUT); // lock condition of synthesizer

  digitalWrite(CSB_A10, HIGH);   // inactive
  digitalWrite(CE_A11, LOW);     // keep synth off until ready

  // SPI1 on Teensy 4.1
  SPI1.setMOSI(SDI_MOSI);
  SPI1.setSCK(SCK_SCK);
  SPI1.begin();

  // Enable synthesizer
  digitalWrite(CE_A11, HIGH);
  delay(10);


}

void loop() 
{
  //start Synthesizer
  digitalWrite(CE_A11, HIGH);

  //main detection section
  float Det_Voltage = analogRead(Detector_V_UP)*(5.0 / 1023.0); // voltage received by Detector
  if(Det_Voltage > 0.05 && Det_Voltage < 0.2)
  {
    //weak signal detected
    digitalWrite(41, LOW);
  }
  if(Det_Voltage > 0.35 && Det_Voltage < 0.5)
  {
    //medium signal detected
    digitalWrite(41, HIGH);
  }
  if(Det_Voltage > 0.5 && Det_Voltage < 1)
  {
    //strong signal detected
    digitalWrite(41, HIGH);
  }



  
}

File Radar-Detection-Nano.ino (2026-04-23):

#include <Wire.h>
#include <Adafruit_GFX.h>
#include <Adafruit_SSD1306.h>

// ── Pin assignments ──────────────────────────────────────────────
const int BUZZER_PIN  = 3;
const int LED_PIN     = 6;
const byte INPUT_PIN  = 2; // Must be an interrupt-capable pin (Nano: 2 or 3)
                            // Pin 6 is NOT interrupt-capable on the Nano —
                            // change this if you meant a different board

// ── Frequency detection ──────────────────────────────────────────
const int MIDDLE_C         = 262;   // Hz
const long SAMPLE_MS       = 500L;  // Sampling window in ms
const float FREQ_THRESHOLD = 10.0;  // Hz — anything above this counts as "detected"

volatile long count          = 0L;
unsigned long prevSampleTime = 0L;

// ── OLED setup ───────────────────────────────────────────────────
#define SCREEN_WIDTH 128
#define SCREEN_HEIGHT 32
#define OLED_RESET -1  // No reset pin
Adafruit_SSD1306 display(SCREEN_WIDTH, SCREEN_HEIGHT, &Wire, OLED_RESET);

// ── ISR ──────────────────────────────────────────────────────────
void addPulse() {
  count++;
} // <-- was missing

void setup() {
  pinMode(LED_PIN,    OUTPUT);
  pinMode(BUZZER_PIN, OUTPUT); // <-- was missing
  pinMode(INPUT_PIN,  INPUT);
  Serial.begin(115200);

  // Start OLED (0x3C is the standard I2C address for most cheap modules)
  if (!display.begin(SSD1306_SWITCHCAPVCC, 0x3C)) {
    Serial.println("OLED not found");
    while (true); // Halt if display missing — helps diagnose wiring issues
  }

  display.clearDisplay();
  display.setTextSize(1);
  display.setTextColor(SSD1306_WHITE);
  display.setCursor(0, 0);
  display.println("Radar ready...");
  display.display();
     delay(1000);

  attachInterrupt(digitalPinToInterrupt(INPUT_PIN), addPulse, RISING);
}

void loop() {
  if (millis() - prevSampleTime >= SAMPLE_MS) {
    prevSampleTime += SAMPLE_MS;

    detachInterrupt(digitalPinToInterrupt(INPUT_PIN));
    long snapshot = count; // Copy before resetting
    count = 0L;
    attachInterrupt(digitalPinToInterrupt(INPUT_PIN), addPulse, RISING);

    // Count was rising edges over SAMPLE_MS, so multiply by 2 to get full cycles
    // if your signal is a clean square wave; remove the *2 if you're unsure
    float frequency = (float)snapshot / (SAMPLE_MS / 1000.0);

    Serial.print(frequency);
    Serial.println(" Hz");

    if (frequency > FREQ_THRESHOLD) {
      // ── Motion detected ─────────────────────────────────────
      digitalWrite(LED_PIN, HIGH);
      tone(BUZZER_PIN, MIDDLE_C, 1000);

      display.clearDisplay();
      display.setTextSize(1);
      display.setCursor(0, 0);
      display.println("DETECTED");
      display.setTextSize(1);
      display.setCursor(0, 28);
      display.print("Freq: ");
      display.print(frequency, 1);
      display.println(" Hz");
      display.display();

      delay(1000);
      digitalWrite(LED_PIN, LOW);
      // tone() stops on its own after the 1000ms duration

    } else {
      // ── No motion ────────────────────────────────────────────
      display.clearDisplay();
      display.setTextSize(1);
      display.setCursor(0, 0);
      display.println("No motion");
      display.setCursor(0, 16);
      display.print("Freq: ");
      display.print(frequency, 1);
      display.println(" Hz");
      display.display();
    }
  }
}

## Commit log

2026-01-26 Horn Antenna
    Matlab code to generate mesh for horn antenna. Along with instructions to import it into FreeCAD and already created FreeCAD files
2026-01-27 Horn Antenna V2
    Created Horn Antenna V2 and organized Files
2026-02-10 Horn Antenna V3 & Organization
    Organized the folders. Additionally, Created V3; this focuses on the Ka band instead of the previous X through Ka Band.
    [8_40Ghz_Scaled.stl, HornAntennaKA.FCStd, horn.stl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]
2026-03-26 Addign files for Evan
    First draft of Teensy code
2026-04-23 Finalized Horn Antenna & Waveguide
    Uploaded Final Horn antenna & Waveguide Models along with updating readme and adding documents folder
    [Antenna.stp, AntennaBOTFillet.step, AntennaTOPFillet.step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]
2026-04-23 Added PCB Files to Github
    [AD8314ARMZ.step, OSHE_RadarDetector_ControlBoard.kicad_pcb, OSHE_RadarDetector_ControlBoard.kicad_sch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]
2026-04-23 Create Spring 2026 - Radar Detector Project Report FINAL.pdf
